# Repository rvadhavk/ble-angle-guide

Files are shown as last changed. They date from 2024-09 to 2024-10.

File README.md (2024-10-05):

# BLE Angle Guide
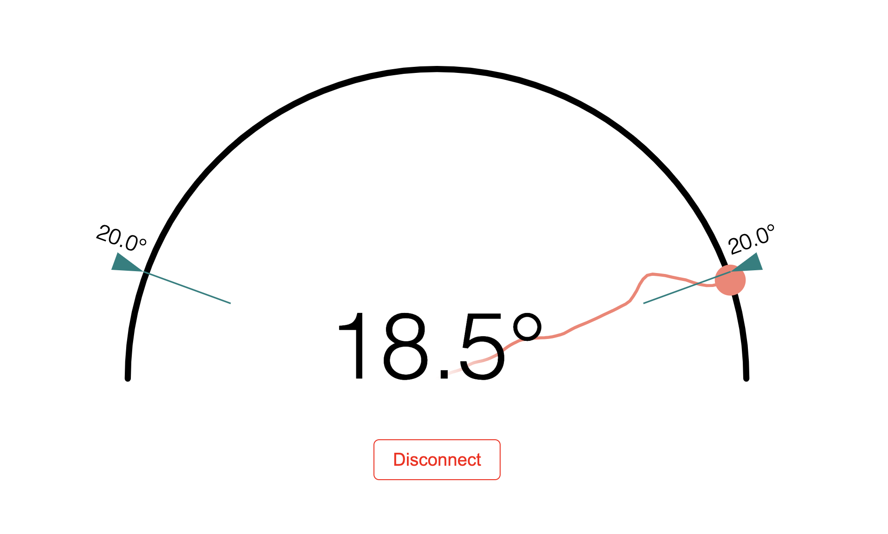
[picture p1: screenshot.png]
screnshot of the gui showing angle readings

This project is my attempt to create a BLE knife sharpening angle guide/sensor that magnetically clips onto the side of your knife. The UI is a webpage which talks to the sensor using WebBluetooth. The hardware is a custom PCB based around a Panasonic nRF52840 module. The firmware is implemented in Rust using <a href="https://github.com/embassy-rs/embassy">Embassy</a>.  It's my first foray into embedded systems, so the PCB design is probably terrible.

## Project Structure
- [hardware/](./hardware): KiCad files for the PCB
- [firmware/](./firmware): Rust firmware for the nRF52840 module
- [ui/](./ui): Web-based UI (just an index.html file)

## Building the Firmware
The board has 1.27mm/0.05" pitch 2x5 pads which can be connected to using something like <https://www.adafruit.com/product/5434>.  For anyone wanting to develop something similar, a 10 pin connector is unnecessary; all you need is 4 pins: SWCLK, SWDIO, GND, and VCC.

To build and debug, run `cargo run --release` from the `firmware` directory.  Note: the CPU seems to hardfault after some time if running without the `--release` flag.  I haven't figured out why yet; I'm guessing it has to do with a stack overflow.

To flash the device, run `sh flash.sh` from the `firmware` directory.

## UI
The UI is just a single [index.html](./ui/index.html) file.  WebBluetooth requires an https connection, so [development-server.py](./ui/development-server.py) is included for running a simple HTTP server with TLS support.  It requires that `mkcert` be installed or that you manually generate `cert.pem` and `key.pem`.

## Known Issues
- On/off button logic hasn't been implemented yet in the firmware
- USB connector is currently unused in firmware

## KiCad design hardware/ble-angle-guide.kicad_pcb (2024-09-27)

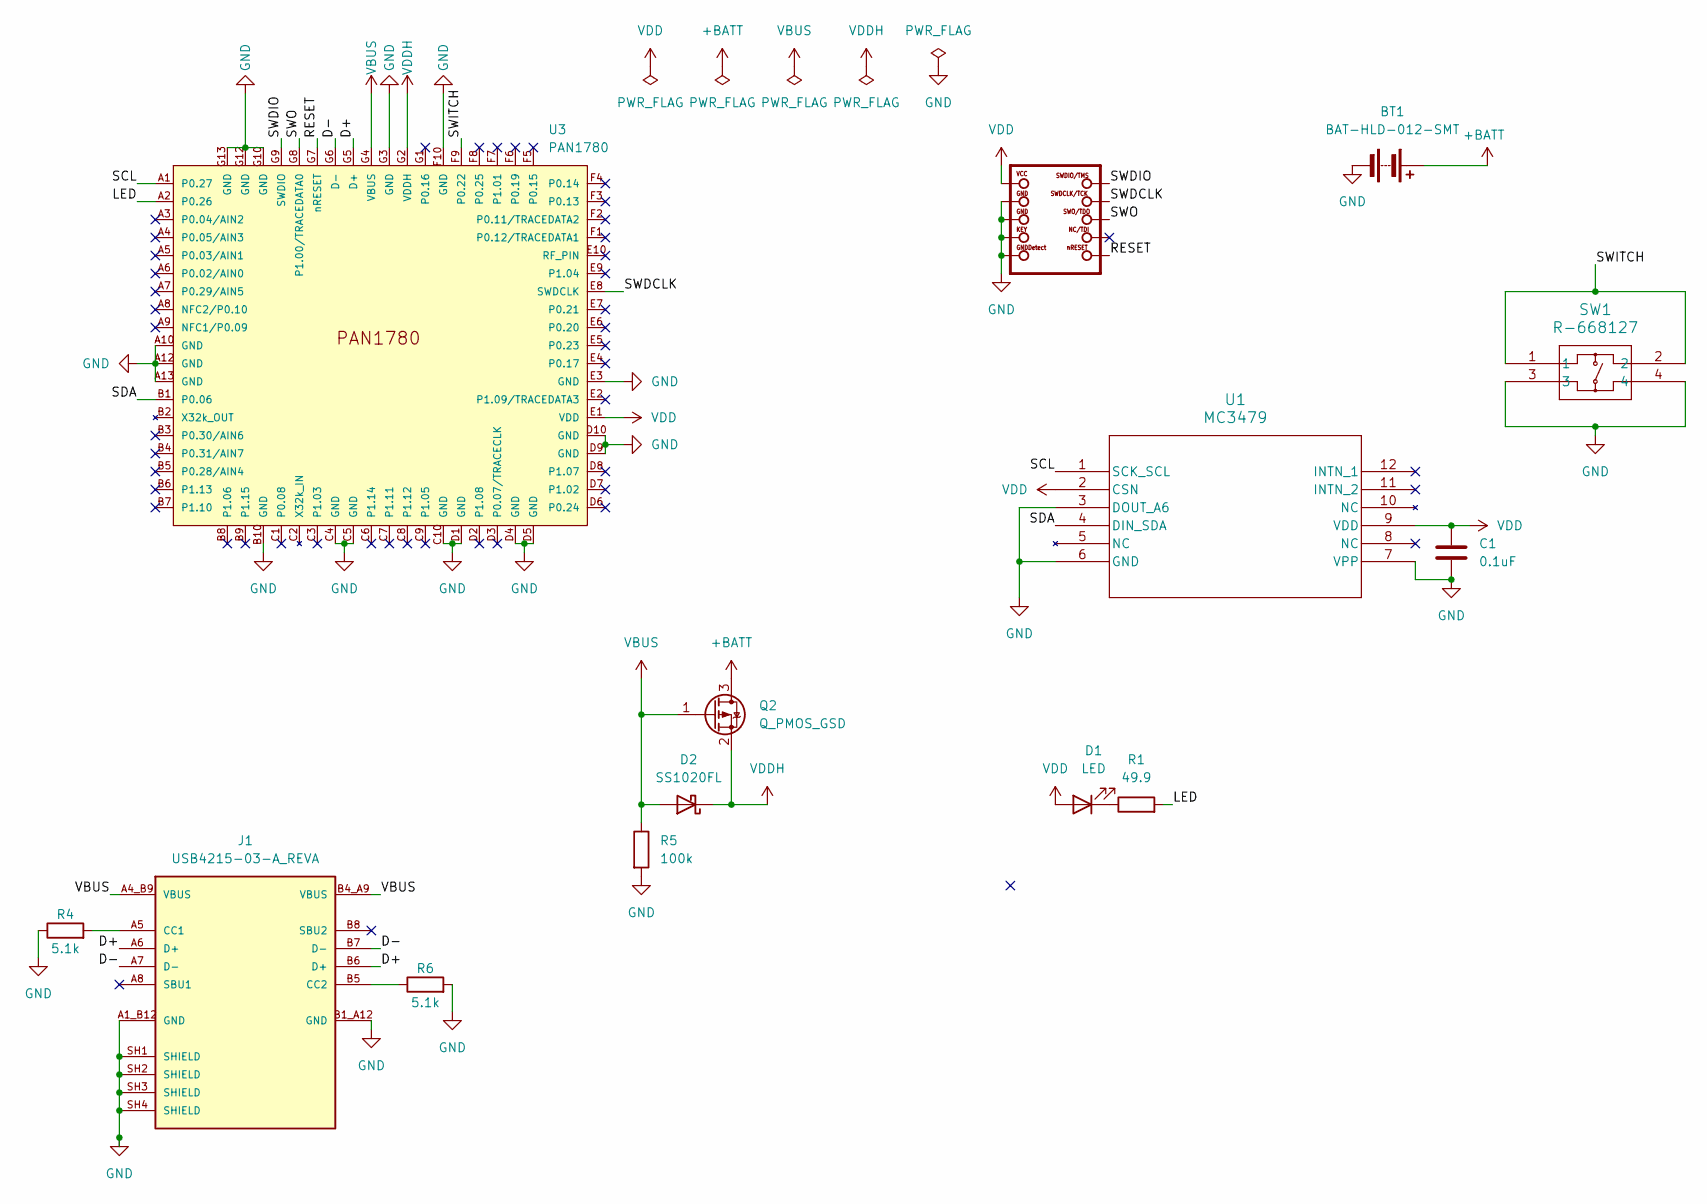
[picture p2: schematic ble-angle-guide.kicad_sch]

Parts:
BT1: BAT-HLD-012-SMT; BAT-HLD-012-SMT_TEC
C1: 0.1uF; CAP_CL05_SAM
D1: LED; LED_0402_1005Metric
D2: SS1020FL
J1: USB4215-03-A_REVA; USB4215-03-A_REVA_GCT_USB4215-03-A_REVA; PARTREV A
Q2: Q_PMOS_GSD; SOT-23
R1: 49.9; R_0402_1005Metric
R4, R6: 5.1k; R_0402_1005Metric
R5: 100k; R_0402_1005Metric
SW1: R-668127; R-668127_MIT
SWD2: SWD Contacts
U1: MC3479; MC3479_MEM
U3: PAN1780; PAN1780_PAN1780FP

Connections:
+BATT: BT1.1 (+), Q2.3 (D)
/D+: J1.A6 (D+), J1.B6 (D+), U3.G5 (D+)
/D-: J1.A7 (D-), J1.B7 (D-), U3.G6 (D-)
/LED: R1.2, U3.A2 (P0.26)
/RESET: SWD2.10 (NRESET), U3.G7 (nRESET); also elsewhere on the board
/SCL: U1.1 (SCK_SCL), U3.A1 (P0.27)
/SDA: U1.4 (DIN_SDA), U3.B1 (P0.06)
/SWDCLK: SWD2.4 (SWDCLK), U3.E8 (SWDCLK); also elsewhere on the board
/SWDIO: SWD2.2 (SWDIO), U3.G9 (SWDIO); also elsewhere on the board
/SWITCH: SW1.1, SW1.2, U3.F9 (P0.22)
/SWO: SWD2.6 (SWO), U3.G8 (P1.00/TRACEDATA0); also elsewhere on the board
GND: BT1.2 (-), C1.2, J1.A1_B12 (GND), J1.B1_A12 (GND), J1.SH1 (SHIELD), J1.SH2 (SHIELD), J1.SH3 (SHIELD), J1.SH4 (SHIELD), R4.1, R5.2, R6.2, SW1.3, SW1.4, SWD2.3 (GND@1), SWD2.5 (GND@2), SWD2.7 (KEY), SWD2.9 (GNDDETECT), U1.3 (DOUT_A6), U1.6 (GND), U1.7 (VPP), U3.A10 (GND), U3.A12 (GND), U3.A13 (GND), U3.B10 (GND), U3.C4 (GND), U3.C5 (GND), U3.C10 (GND), U3.D1 (GND), U3.D4 (GND), U3.D5 (GND), U3.D9 (GND), U3.D10 (GND), U3.E3 (GND), U3.F10 (GND), U3.G3 (GND), U3.G10 (GND), U3.G12 (GND), U3.G13 (GND); also elsewhere on the board
unnamed: D1.1 (K), R1.1
unnamed: J1.A5 (CC1), R4.2
unnamed: J1.B5 (CC2), R6.1
VBUS: D2.2 (A), J1.A4_B9 (VBUS), J1.B4_A9 (VBUS), Q2.1 (G), R5.1, U3.G4 (VBUS)
VDD: C1.1, D1.2 (A), SWD2.1 (VCC), U1.2 (CSN), U1.9 (VDD), U3.E1 (VDD); also elsewhere on the board
VDDH: D2.1 (K), Q2.2 (S), U3.G2 (VDDH)

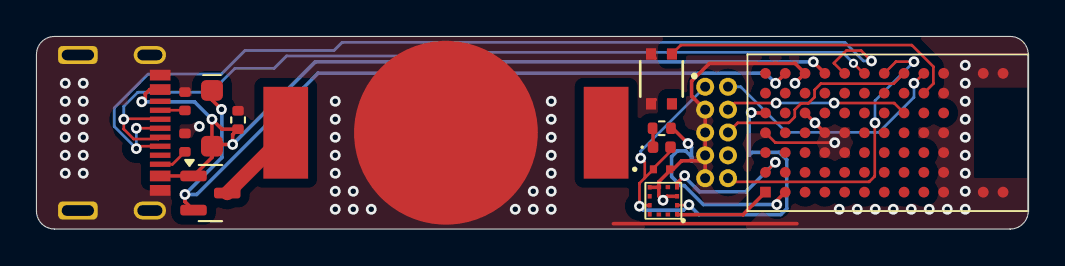
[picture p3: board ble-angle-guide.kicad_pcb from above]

Board: 2 copper layers, 55.1 x 10.7 mm, 14 parts (0 on the bottom side), 18 nets.

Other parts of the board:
SWD1: SWD Contacts

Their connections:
/RESET: SWD1.10 (NRESET); also elsewhere on the board
/SWDCLK: SWD1.4 (SWDCLK); also elsewhere on the board
/SWDIO: SWD1.2 (SWDIO); also elsewhere on the board
/SWO: SWD1.6 (SWO); also elsewhere on the board
GND: SWD1.3 (GND@1), SWD1.5 (GND@2), SWD1.7 (KEY), SWD1.9 (GNDDETECT); also elsewhere on the board
VDD: SWD1.1 (VCC); also elsewhere on the board

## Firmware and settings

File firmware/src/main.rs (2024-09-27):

#![no_std]
#![no_main]

use core;
use core::mem;
use defmt::*;
use defmt_rtt as _; // global logger
use embassy_executor::Spawner;
use embassy_nrf as _; // time driver
use embassy_nrf::interrupt::{self, InterruptExt, Priority};
use embassy_nrf::twim::{self, Twim};
use embassy_nrf::{bind_interrupts, peripherals};
use embassy_time::{Duration, Timer};
use embedded_hal::i2c::I2c;
use futures::future::select;
use futures::pin_mut;
use nrf_softdevice::ble::advertisement_builder::{Flag, LegacyAdvertisementBuilder, ServiceList};
use nrf_softdevice::ble::{
    gatt_server,
    peripheral::{self, advertise_connectable},
};
use nrf_softdevice::{raw, Softdevice};
use panic_probe as _;

#[embassy_executor::task]
async fn softdevice_task(sd: &'static Softdevice) -> ! {
    sd.run().await
}

// Needed for TWIM for some reason
bind_interrupts!(struct Irqs {
    SPIM0_SPIS0_TWIM0_TWIS0_SPI0_TWI0 => twim::InterruptHandler<peripherals::TWISPI0>;
});

struct AccelerometerDriver<I2C: I2c> {
    i2c: I2C,
}

impl<I2C: I2c> AccelerometerDriver<I2C> {
    pub fn new(i2c: I2C) -> Self {
        Self { i2c }
    }

    const ADDRESS: u8 = 0x4c;

    pub fn reset(&mut self) -> Result<(), I2C::Error> {
        self.sleep()?;
        self.configure()?;
        self.wake()
    }

    pub fn sleep(&mut self) -> Result<(), I2C::Error> {
        self.i2c.write(Self::ADDRESS, &[0x07, 0x00])
    }

    pub fn wake(&mut self) -> Result<(), I2C::Error> {
        self.i2c.write(Self::ADDRESS, &[0x07, 0x01])
    }

    pub fn configure(&mut self) -> Result<(), I2C::Error> {
        // setup low pass filter
        self.i2c.write(Self::ADDRESS, &[0x20, 0b0000_1101])?;
        // set internal data rate
        self.i2c.write(Self::ADDRESS, &[0x08, 0x00])?;
        // set decimation
        self.i2c.write(Self::ADDRESS, &[0x30, 0b00])
    }

    pub fn read_xyz(&mut self) -> Result<[u8; 6], I2C::Error> {
        let mut buf = [0u8; 6];
        self.i2c.write_read(Self::ADDRESS, &[0x0d], &mut buf)?;
        Ok(buf)
    }
}

#[nrf_softdevice::gatt_service(uuid = "b3f787c6-77c9-49c1-bd93-3692eb94d2ca")]
struct AccelerometerService {
    #[characteristic(uuid = "6ec6e014-9fe0-4e14-97a1-bbf221d19dec", read, notify)]
    xyz: [u8; 6],
}

#[nrf_softdevice::gatt_server]
struct Server {
    accelerometer: AccelerometerService,
}

const DEVICE_NAME: &str = "Inclinometer";

async fn run_bluetooth(
    sd: &'static Softdevice,
    server: &Server,
    accelerometer: &mut AccelerometerDriver<impl I2c>,
) {
    let advertisement = peripheral::ConnectableAdvertisement::ScannableUndirected {
        adv_data: &LegacyAdvertisementBuilder::new()
            .flags(&[Flag::GeneralDiscovery, Flag::LE_Only])
            .full_name(DEVICE_NAME)
            .build(),
        scan_data: &LegacyAdvertisementBuilder::new()
            .services_128(
                ServiceList::Complete,
                &[0xb3f787c6_77c9_49c1_bd93_3692eb94d2ca_u128.to_le_bytes()],
            )
            .build(),
    };
    info!("Advertising...");
    let conn = unwrap!(advertise_connectable(sd, advertisement, &Default::default()).await);
    info!("Connected!");
    accelerometer.reset().unwrap();
    let accelerometer_read_task = async {
        loop {
            let xyz = match accelerometer.read_xyz() {
                Ok(xyz) => xyz,
                Err(_) => {
                    error!("Failed to read xyz");
                    [0; 6]
                }
            };
            if let Err(e) = server.accelerometer.xyz_set(&xyz) {
                error!("Failed to set xyz: {:?}", e);
            }
            if let Err(e) = server.accelerometer.xyz_notify(&conn, &xyz) {
                error!("Failed to notify xyz: {:?}", e);
            }
            Timer::after(Duration::from_millis(33)).await;
        }
    };

    let server_task = gatt_server::run(&conn, server, |_| {});
    pin_mut!(accelerometer_read_task);
    pin_mut!(server_task);
    let _ = select(accelerometer_read_task, server_task).await;
    accelerometer.sleep().unwrap();
}

#[embassy_executor::main]
async fn main(spawner: Spawner) {
    info!("Starting...");


    let peripherals = embassy_nrf::init({
        let mut config = embassy_nrf::config::Config::default();
        // These need to be lower priority than softdevice interrupts
        config.gpiote_interrupt_priority = Priority::P2;
        config.time_interrupt_priority = Priority::P2;
        config
    });
    let sd = Softdevice::enable(&nrf_softdevice::Config {
        gap_device_name: Some(raw::ble_gap_cfg_device_name_t {
            p_value: DEVICE_NAME.as_bytes().as_ptr() as _,
            current_len: DEVICE_NAME.len() as _,
            max_len: DEVICE_NAME.len() as _,
            write_perm: unsafe { mem::zeroed() },
            _bitfield_1: raw::ble_gap_cfg_device_name_t::new_bitfield_1(
                raw::BLE_GATTS_VLOC_STACK as u8,
            ),
        }),
        ..Default::default()
    });

    info!("Initializing TWI...");
    let (twi0, sda, scl) = (peripherals.TWISPI0, peripherals.P0_06, peripherals.P0_27);
    interrupt::SPIM0_SPIS0_TWIM0_TWIS0_SPI0_TWI0.set_priority(Priority::P3);
    let twi = Twim::new(twi0, Irqs, sda, scl, {
        let mut config = twim::Config::default();
        config.scl_pullup = true;
        config.sda_pullup = true;
        config
    });

    let mut accelerometer = AccelerometerDriver::new(twi);
    let server = unwrap!(Server::new(sd));
    unwrap!(spawner.spawn(softdevice_task(sd)));
    loop {
        run_bluetooth(sd, &server, &mut accelerometer).await;
    }
}
